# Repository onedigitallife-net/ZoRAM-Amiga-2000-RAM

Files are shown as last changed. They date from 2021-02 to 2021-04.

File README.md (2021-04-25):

# ZoRAM - Eight Megabyte Fast RAM Expansion for the Amiga 2000

This project is early in development. It may or may not work at this time.

I have always felt big box Amiga's should be used as intended. Expansion should be targeted to the expansion slots provided. This project aims to provde an 8 megabyte expansion option via the Zorro II bus of the Amiga 2000. Based on LIV2's GottaGoFastRAM for 68000 DIP based Amigas. Due to the relative messiness of the  data and address line locations on the Zorro II connector, it was necessary to  change the connection points on the Xilinx. As such, the JED file for this project is specific to this project and cannot be interchanged with LIV2's original.

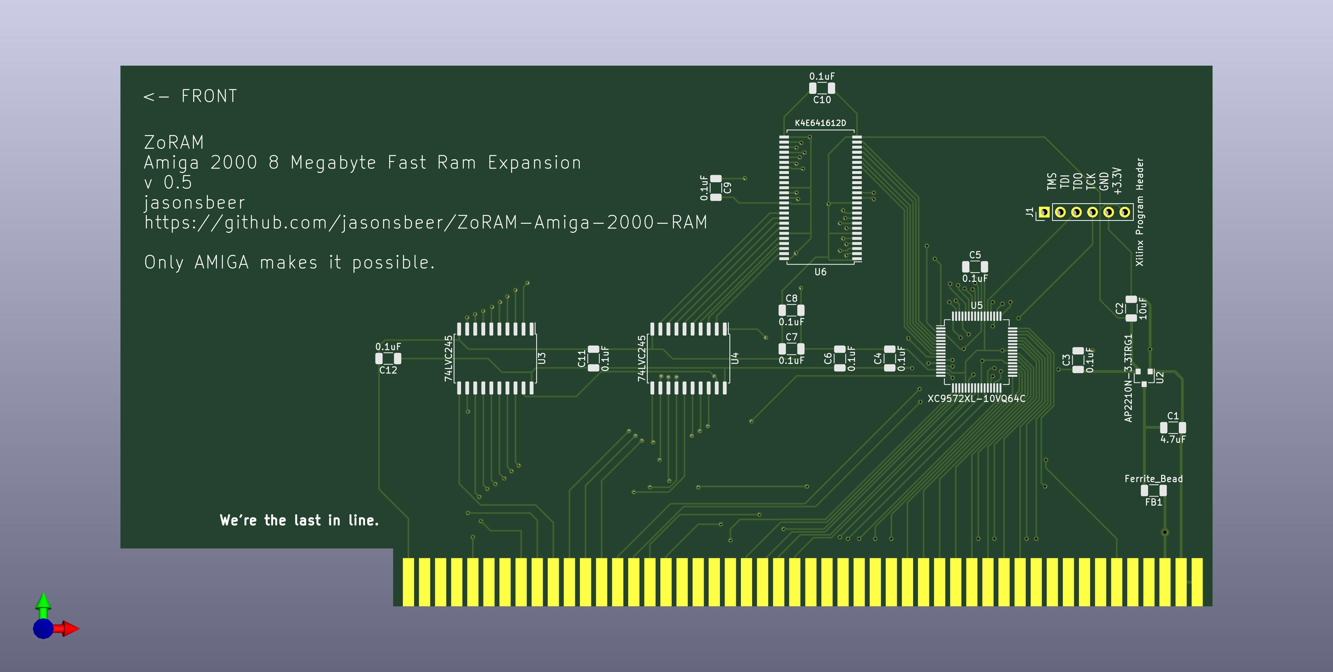
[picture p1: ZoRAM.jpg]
ZoRAM Image


# PCB Ordering and Assembly

Under construction

# Programming the CPLD

To be completed later.

# BOM

|Component|Package|Location|QTY|Source|Part Number|
--- | --- | --- | --- | --- | ---
4Mx16 DRAM|TSOP(II)| U6 | 1 | Ali Express or E-Bay| K4E641612D or GM71VS65163
XC9572XL-10VQ64C|64-VQFP|U5|1|DigiKey|122-1266-ND or 122-1982-ND
AP2210N-3.3TRG1|SOT-23-3|U2|1|DigiKey|AP2210N-3.3TRG1DICT-ND
SN74LVC245A|SOIC|U3,U4|2|DigiKey|296-1232-1-ND
Ferrite Bead (600 Ohms@100MHz)|1206|FB1|1|DigiKey|MH3261-601YCT-ND
0.1uF Ceramic Capacitor|1206|C3-12|10|DigiKey|1276-2744-1-ND
4.7uF Ceramic Capacitor|1206|C1|1|DigiKey|1276-1055-1-ND
10uF Ceramic Capacitor|1206|C2|1|DigiKey|1276-1853-1-ND
6 Pin Male 2.54 Pitch Header (Optional)|--|J1|1|DigiKey|1849-PR20206VBNN-ND‎

# Revision History

V0.5 - Prototype Revision

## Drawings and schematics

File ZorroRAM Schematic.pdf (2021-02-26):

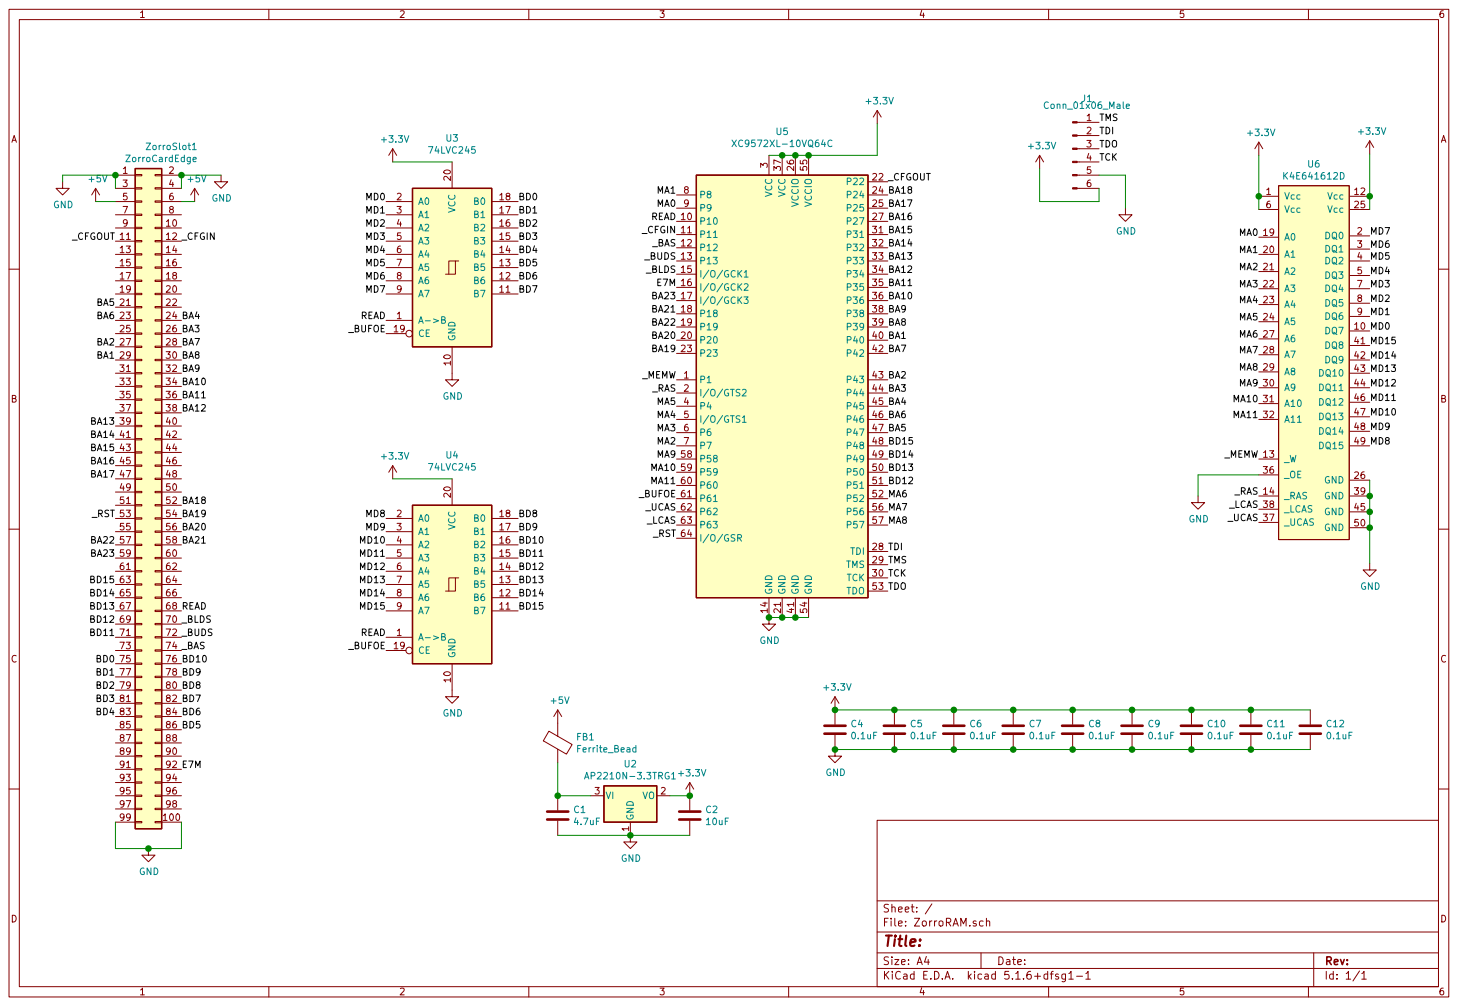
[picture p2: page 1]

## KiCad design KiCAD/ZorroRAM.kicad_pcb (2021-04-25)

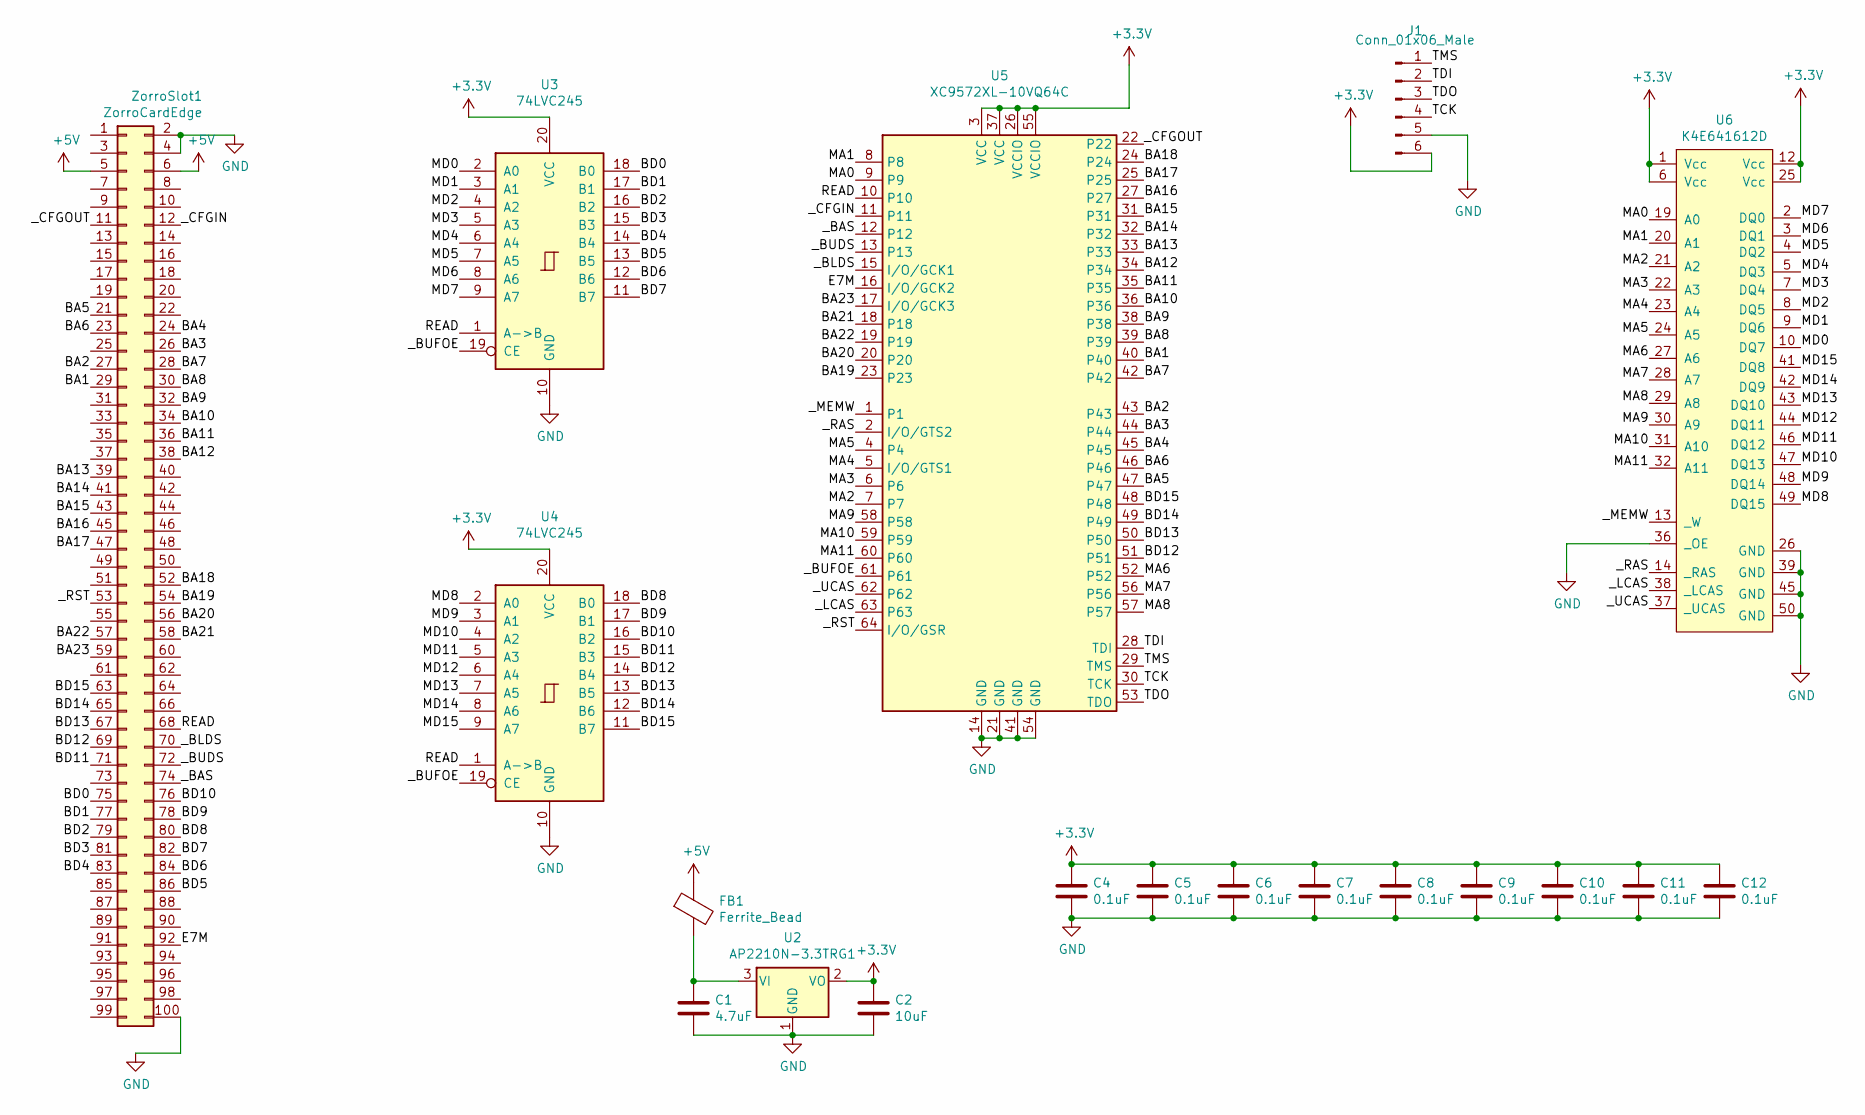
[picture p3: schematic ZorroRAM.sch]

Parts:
C1: 4.7uF; C_1206_3216Metric
C2: 10uF; C_1206_3216Metric
C4, C5, C6, C7, C8, C9, C10, C11, C12: 0.1uF; C_1206_3216Metric
FB1: Ferrite_Bead; C_1206_3216Metric
J1: Conn_01x06_Male; PinHeader_1x06_P2.54mm_Vertical
U2: AP2210N-3.3TRG1; SOT-23
U3, U4: 74LVC245; SOIC-20W_7.5x12.8mm_P1.27mm
U5: XC9572XL-10VQ64C; TQFP-64_10x10mm_P0.5mm
U6: K4E641612D; TSOP-II-50_P0.8mm
ZorroSlot1: ZorroCardEdge

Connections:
+3V3: C2.1, C4.1, C5.1, C6.1, C7.1, C8.1, C9.1, C10.1, C11.1, C12.1, J1.6, U2.2 (VO), U3.20 (VCC), U4.20 (VCC), U5.3 (VCC), U5.26 (VCCIO), U5.37 (VCC), U5.55 (VCCIO), U6.1 (Vcc), U6.6 (Vcc), U6.12 (Vcc), U6.25 (Vcc)
+5V: FB1.1, ZorroSlot1.5, ZorroSlot1.6
/BA1: U5.40, ZorroSlot1.29
/BA2: U5.43, ZorroSlot1.27
/BA3: U5.44, ZorroSlot1.26
/BA4: U5.45, ZorroSlot1.24
/BA5: U5.47, ZorroSlot1.21
/BA6: U5.46, ZorroSlot1.23
/BA7: U5.42, ZorroSlot1.28
/BA8: U5.39, ZorroSlot1.30
/BA9: U5.38, ZorroSlot1.32
/BA10: U5.36, ZorroSlot1.34
/BA11: U5.35, ZorroSlot1.36
/BA12: U5.34, ZorroSlot1.38
/BA13: U5.33, ZorroSlot1.39
/BA14: U5.32, ZorroSlot1.41
/BA15: U5.31, ZorroSlot1.43
/BA16: U5.27, ZorroSlot1.45
/BA17: U5.25, ZorroSlot1.47
/BA18: U5.24, ZorroSlot1.52
/BA19: U5.23, ZorroSlot1.54
/BA20: U5.20, ZorroSlot1.56
/BA21: U5.18, ZorroSlot1.58
/BA22: U5.19, ZorroSlot1.57
/BA23: U5.17 (I/O/GCK3), ZorroSlot1.59
/BD0: U3.18 (B0), ZorroSlot1.75
/BD1: U3.17 (B1), ZorroSlot1.77 (Pin77)
/BD2: U3.16 (B2), ZorroSlot1.79 (Pin79)
/BD3: U3.15 (B3), ZorroSlot1.81 (Pin81)
/BD4: U3.14 (B4), ZorroSlot1.83 (Pin83)
/BD5: U3.13 (B5), ZorroSlot1.86 (Pin86)
/BD6: U3.12 (B6), ZorroSlot1.84 (Pin84)
/BD7: U3.11 (B7), ZorroSlot1.82 (Pin82)
/BD8: U4.18 (B0), ZorroSlot1.80 (Pin80)
/BD9: U4.17 (B1), ZorroSlot1.78 (Pin78)
/BD10: U4.16 (B2), ZorroSlot1.76 (Pin76)
/BD11: U4.15 (B3), ZorroSlot1.71
/BD12: U4.14 (B4), U5.51, ZorroSlot1.69
/BD13: U4.13 (B5), U5.50, ZorroSlot1.67
/BD14: U4.12 (B6), U5.49, ZorroSlot1.65
/BD15: U4.11 (B7), U5.48, ZorroSlot1.63
/E7M: U5.16 (I/O/GCK2), ZorroSlot1.92 (Pin92)
/MA0: U5.9, U6.19 (A0)
/MA1: U5.8, U6.20 (A1)
/MA2: U5.7, U6.21 (A2)
/MA3: U5.6, U6.22 (A3)
/MA4: U5.5 (I/O/GTS1), U6.23 (A4)
/MA5: U5.4, U6.24 (A5)
/MA6: U5.52, U6.27 (A6)
/MA7: U5.56, U6.28 (A7)
/MA8: U5.57, U6.29 (A8)
/MA9: U5.58, U6.30 (A9)
/MA10: U5.59, U6.31 (A10)
/MA11: U5.60, U6.32 (A11)
/MD0: U3.2 (A0), U6.10 (DQ7)
/MD1: U3.3 (A1), U6.9 (DQ6)
/MD2: U3.4 (A2), U6.8 (DQ5)
/MD3: U3.5 (A3), U6.7 (DQ4)
/MD4: U3.6 (A4), U6.5 (DQ3)
/MD5: U3.7 (A5), U6.4 (DQ2)
/MD6: U3.8 (A6), U6.3 (DQ1)
/MD7: U3.9 (A7), U6.2 (DQ0)
/MD8: U4.2 (A0), U6.49 (DQ15)
/MD9: U4.3 (A1), U6.48 (DQ14)
/MD10: U4.4 (A2), U6.47 (DQ13)
/MD11: U4.5 (A3), U6.46 (DQ12)
/MD12: U4.6 (A4), U6.44 (DQ11)
/MD13: U4.7 (A5), U6.43 (DQ10)
/MD14: U4.8 (A6), U6.42 (DQ9)
/MD15: U4.9 (A7), U6.41 (DQ8)
/READ: U3.1 (A->B), U4.1 (A->B), U5.10, ZorroSlot1.68
/TCK: J1.4, U5.30 (TCK)
/TDI: J1.2, U5.28 (TDI)
/TDO: J1.3, U5.53 (TDO)
/TMS: J1.1, U5.29 (TMS)
/_BAS: U5.12, ZorroSlot1.74
/_BLDS: U5.15 (I/O/GCK1), ZorroSlot1.70
/_BUDS: U5.13, ZorroSlot1.72 (_BUDS)
/_BUFOE: U3.19 (CE), U4.19 (CE), U5.61
/_CFGIN: U5.11, ZorroSlot1.12
/_CFGOUT: U5.22, ZorroSlot1.11
/_LCAS: U5.63, U6.38 (_LCAS)
/_MEMW: U5.1, U6.13 (_W)
/_RAS: U5.2 (I/O/GTS2), U6.14 (_RAS)
/_RST: U5.64 (I/O/GSR), ZorroSlot1.53
/_UCAS: U5.62, U6.37 (_UCAS)
GND: C1.2, C2.2, C4.2, C5.2, C6.2, C7.2, C8.2, C9.2, C10.2, C11.2, C12.2, J1.5, U2.1 (GND), U3.10 (GND), U4.10 (GND), U5.14 (GND), U5.21 (GND), U5.41 (GND), U5.54 (GND), U6.26 (GND), U6.36 (_OE), U6.39 (GND), U6.45 (GND), U6.50 (GND), ZorroSlot1.2, ZorroSlot1.4, ZorroSlot1.100 (Pin100)
unnamed: C1.1, FB1.2, U2.3 (VI)

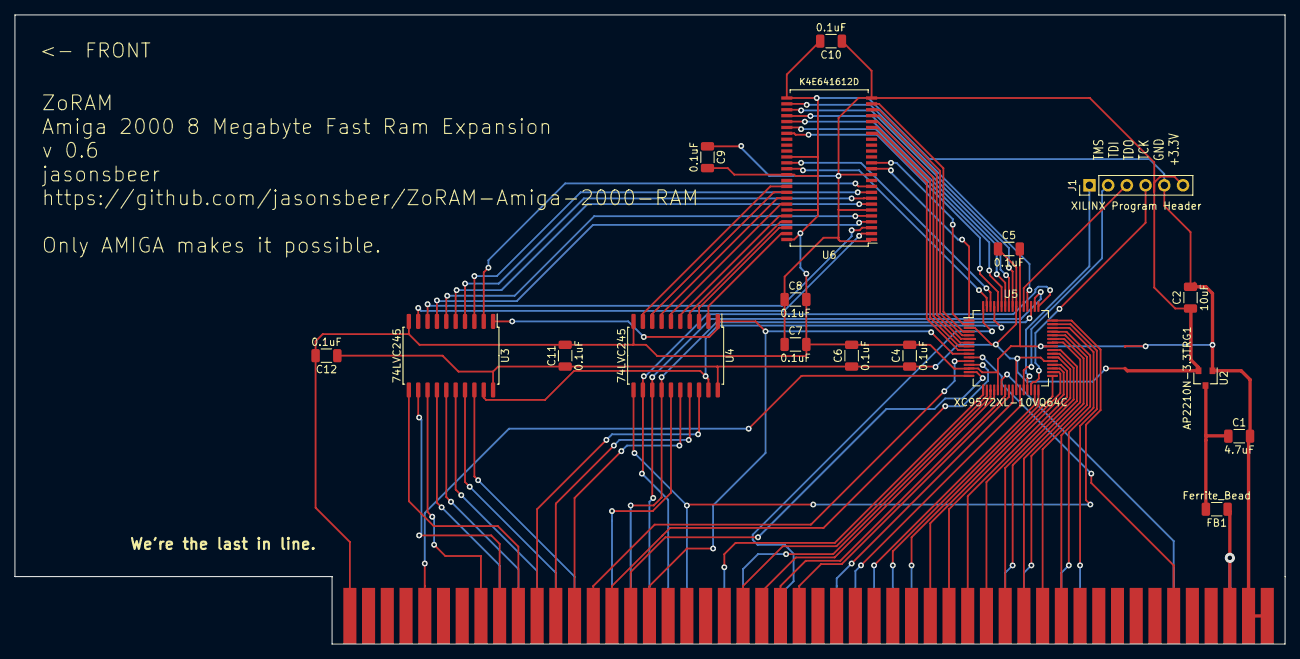
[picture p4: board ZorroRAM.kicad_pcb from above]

Board: 2 copper layers, 172.3 x 85.3 mm, 19 parts (0 on the bottom side), 88 nets.

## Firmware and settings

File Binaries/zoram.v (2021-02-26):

/*
8MB Autoconfig FastRAM for Amiga 2000
Original Copyright 2020 Matthew Harlum
Modificiations for ZoRAM 2021 Jason Neus

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
*/

// Config defines
`define autoconfig  // If disabled RAM is always mapped to $200000-9FFFFF
`define rev_b

module zoram(
    input CLK,
    input RESETn,
    input CFGINn,
    input UDSn,
    input LDSn,
    input ASn,
    input RWn,
    inout [15:12] DBUS,
    input [23:1] ADDR,
    output reg [11:0] MADDR,
    output reg CFGOUTn,
    output RASn,
    output UCASn,
    output LCASn,
    output OEn,
    output MEMWn
    );

reg reset_delayed1;
reg reset;

// Memory controller

reg ram_cycle;
reg access_ras;
reg access_ucas;
reg access_lcas;
reg refresh_ras;
reg refresh_cas;
reg [7:0] addr_match;

`ifdef autoconfig
// Autoconfig
localparam [15:0] mfg_id  = 16'h07DB;
localparam [7:0]  prod_id = 8'd69;
localparam [15:0] serial  = 16'd421;

wire autoconfig_cycle;
reg shutup = 0;
reg CFGINnr;
reg configured;
reg [2:0] autoconfig_state;
reg [3:0] data_out;

localparam Offer_8M = 3'b000,
// If offering 2MB + 4MB blocks you need to offer the 2MB block first
// This is because of a kickstart bug where the memory config overflows if there is already 2MB configured before another 4MB then 2MB is configured...
`ifdef Offer_6M
        Offer_2M = 3'b001,
        Offer_4M = 3'b010,
`else
        Offer_4M = 3'b001,
        Offer_2M = 3'b010,
`endif
        Offer_1M = 3'b011,
        SHUTUP   = 3'b100;

assign DBUS[15:12] = (RESETn & autoconfig_cycle & RWn & !ASn & !UDSn) ? data_out[3:0] : 'bZ;

assign autoconfig_cycle = (ADDR[23:16] == 8'hE8) & !CFGINnr & !shutup;

// Register Config in/out at end of bus cycle
always @(posedge ASn or negedge reset)
begin
  if (!reset) begin
    CFGOUTn <= 1'b1;
    CFGINnr <= 1'b1;
  end else begin
    CFGOUTn <= !shutup;
    CFGINnr <= CFGINn;
  end
end

// Offers an 8MB block first, if there's no space offer 4MB, 2MB then 1MB before giving up
always @(posedge CLK or negedge reset)
begin
  if (!reset) begin
    data_out <= 'bZ;
  end else if (autoconfig_cycle & RWn) begin
    case (ADDR[8:1])
      8'h00:   data_out <= 4'b1110;
      8'h01: 
        case (autoconfig_state)
          Offer_8M: data_out <= 4'b0000;
          Offer_4M: data_out <= 4'b0111;
          Offer_2M: data_out <= 4'b0110;
          Offer_1M: data_out <= 4'b0101;
          default:  data_out <= 4'b0000;
        endcase
      8'h02:   data_out <= ~prod_id[7:4]; // Product number
      8'h03:   data_out <= ~prod_id[3:0]; // Product number
      8'h04:   data_out <= ~4'b1000;
      8'h05:   data_out <= ~4'b0000;
      8'h08:   data_out <= ~mfg_id[15:12]; // Manufacturer ID
      8'h09:   data_out <= ~mfg_id[11:8];  // Manufacturer ID
      8'h0A:   data_out <= ~mfg_id[7:4];   // Manufacturer ID
      8'h0B:   data_out <= ~mfg_id[3:0];   // Manufacturer ID
      8'h10:   data_out <= ~serial[15:12]; // Serial number
      8'h11:   data_out <= ~serial[11:8];  // Serial number
      8'h12:   data_out <= ~serial[7:4];   // Serial number
      8'h13:   data_out <= ~serial[3:0];   // Serial number
      8'h20:   data_out <= 4'b0;
      8'h21:   data_out <= 4'b0;
      default: data_out <= 4'hF;
    endcase
  end
end

always @(negedge UDSn or negedge reset)
begin
  if (!reset) begin
    configured <= 1'b0;
    shutup <= 1'b0;
    addr_match <= 8'b00000000;
    autoconfig_state <= Offer_8M;
  end else if (autoconfig_cycle & !ASn & !RWn) begin
    if (ADDR[8:1] == 8'h26) begin
      // We've been told to shut up (not enough memory space)
      // Try offering a smaller block
      if (autoconfig_state >= SHUTUP-1) begin
        // All options exhausted - time to shut up!
        shutup <= 1;
        autoconfig_state <= SHUTUP;
      end else begin
        // Offer the next smallest block
        autoconfig_state <= autoconfig_state + 1;
      end
    end
    else if (ADDR[8:1] == 8'h24) begin
      case (autoconfig_state)
        Offer_8M:
          begin
            addr_match <= 8'hFF;
            shutup     <= 1'b1;
          end
        Offer_4M:
          begin
            case(DBUS)
              4'h2:    addr_match <= (addr_match|8'b00001111);
              4'h4:    addr_match <= (addr_match|8'b00111100);
              4'h6:    addr_match <= (addr_match|8'b11110000);
            endcase
            shutup     <= 1'b1;
          end
        Offer_2M:
          begin
            case(DBUS)
              4'h2:    addr_match <= (addr_match|8'b00000011);
              4'h4:    addr_match <= (addr_match|8'b00001100);
              4'h6:    addr_match <= (addr_match|8'b00110000);
              4'h8:    addr_match <= (addr_match|8'b11000000);
            endcase
            `ifdef Offer_6M
            autoconfig_state <= Offer_4M;
            `else
            shutup     <= 1'b1;
            `endif
          end
        Offer_1M:
          begin
            case(DBUS)
              4'h2:    addr_match <= (addr_match|8'b00000001);
              4'h3:    addr_match <= (addr_match|8'b00000010);
              4'h4:    addr_match <= (addr_match|8'b00000100);
              4'h5:    addr_match <= (addr_match|8'b00001000);
              4'h6:    addr_match <= (addr_match|8'b00010000);
              4'h7:    addr_match <= (addr_match|8'b00100000);
              4'h8:    addr_match <= (addr_match|8'b01000000);
              4'h9:    addr_match <= (addr_match|8'b10000000);
            endcase
            shutup     <= 1'b1;
          end
        default:  addr_match <= 8'b0;
      endcase
      configured <= 1'b1;
    end
  end
end
`endif

// Memory controller

assign RASn  = !(access_ras | (refresh_ras & refresh_cas));
assign UCASn = !((access_ucas) | refresh_cas);
assign LCASn = !((access_lcas) | refresh_cas);
`ifdef rev_b  // On Rev B OEn drives the buffers
assign OEn   = !ram_cycle | ASn | !RESETn | (UDSn & LDSn);
`else
assign OEn   = !(RWn & access_ras);
`endif
assign MEMWn = RWn | (UDSn & LDSn);

// Filter reset line by registering it
always @(posedge CLK)
begin
  reset_delayed1 <= RESETn;
  reset <= reset_delayed1;
end

// CAS before RAS refresh
// CAS Asserted in S1 & S2
// RAS Asserted in S2
always @(negedge CLK or negedge reset)
begin
  if (!reset) begin
    refresh_cas <= 1'b0;
  end else begin
    refresh_cas <= (!refresh_cas & ASn & !access_ras);
  end
end

always @(posedge CLK or negedge reset)
begin
  if (!reset) begin
    refresh_ras <= 1'b0;
  end else begin
    refresh_ras <= refresh_cas;
  end
end
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

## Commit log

2021-02-24 Create Gerber
2021-02-24 Add Gerbers

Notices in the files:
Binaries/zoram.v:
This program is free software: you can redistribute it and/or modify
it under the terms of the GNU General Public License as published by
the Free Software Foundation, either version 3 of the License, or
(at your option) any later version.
